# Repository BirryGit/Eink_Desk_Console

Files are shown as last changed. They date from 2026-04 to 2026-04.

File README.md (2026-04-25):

Screen_Holder_Thing_2026-Apr-03_04-33-51AM-000_CustomizedView44042802966_png

# Eink_Desk_Console
This is a project I am building to track my projects and show data from Home Assistant and other APIs. I wanted a small thing on my desk that I could glance at and see everything I could possibly want. I also wanted something to keep me on track with time sensitive projects. (So I therefore procrastinated with a project to reduce procrastination.) I don't really recommend anyone build this, because it is incredibly hyperspecific to my use case. Please use it for help and inspiration.

## APIs Needed
1. Open Weather
2. Home Assistant (Self Hosted)
3. Geoapify
4. Google Apps Script

## Bill Of Materials
| Name | Purpose | Quantity | Total Cost (USD) | Link | Distributor |
|---|---|---|---|---|---|
| M2 Bolts | Connecting everything together | 8 | 0.08 | | Amazon |
| USB C Cable | Power and data to the controller | 1 | 4.5 | | Anywhere |
| Xiao ESP32 S3 | Does all the beep booping in this project | 1 | 16.99 | https://www.amazon.com/ESP32S3-2-4GHz-Dual-core-Supported-Efficiency-Interface/dp/B0BYSB66S5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 | Amazon |
| M2 Heat Set Inserts | Adding Threads for 3d Prints | 8 | 0.24 | | Amazon |
| 7.5inch E-Ink Display | It is the main component in the project. It will show the data I need without using basically any power. | 1 | 75.15 | https://www.amazon.com/waveshare-7-5inch-HAT-Raspberry-Consumption/dp/B075R4QY3L#averageCustomerReviewsAnchor | Amazon |

## Wiring Diagram
Driver Board

## Assembly Instructions
1. Print all of the pieces needed (2 case, 1 base)
2. Use heat set inserts to add threads to the printed holes (8 holes on the bezel piece)
3. Place the screen within the bezel
4. Carefully place the backing print into the bezel to keep the screen in place
5. Screw bolts to keep the printed pieces together
6. Put the case into the base, and screw it in
7. Connect the electronics to the screen
   
### Assembly Animation

https://github.com/user-attachments/assets/f419b6c7-1fa8-42ba-b154-1aed95d2b339

Screen_Holder_Thing_2026-Apr-03_04-26-18AM-000_CustomizedView27974898632_png

Screen_Case_2026-Apr-02_05-09-52AM-000_CustomizedView14609026417_png

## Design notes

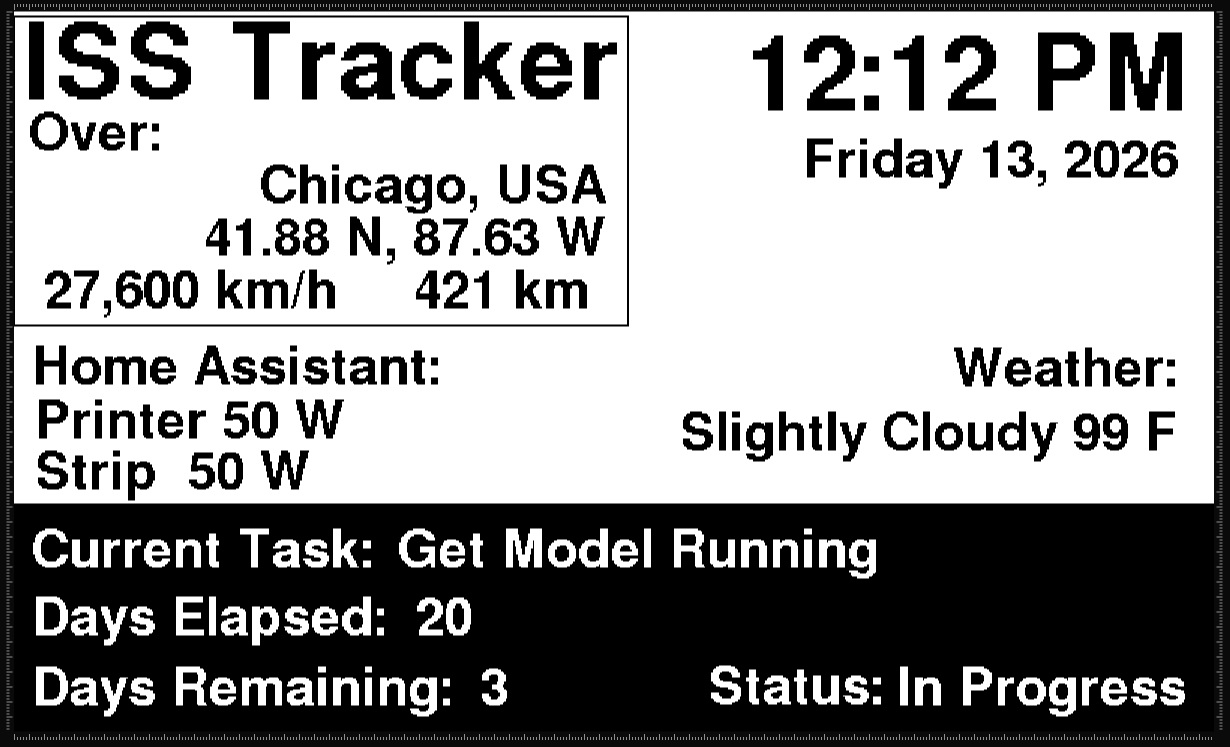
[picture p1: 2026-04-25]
UI/UI_Screenshot.png

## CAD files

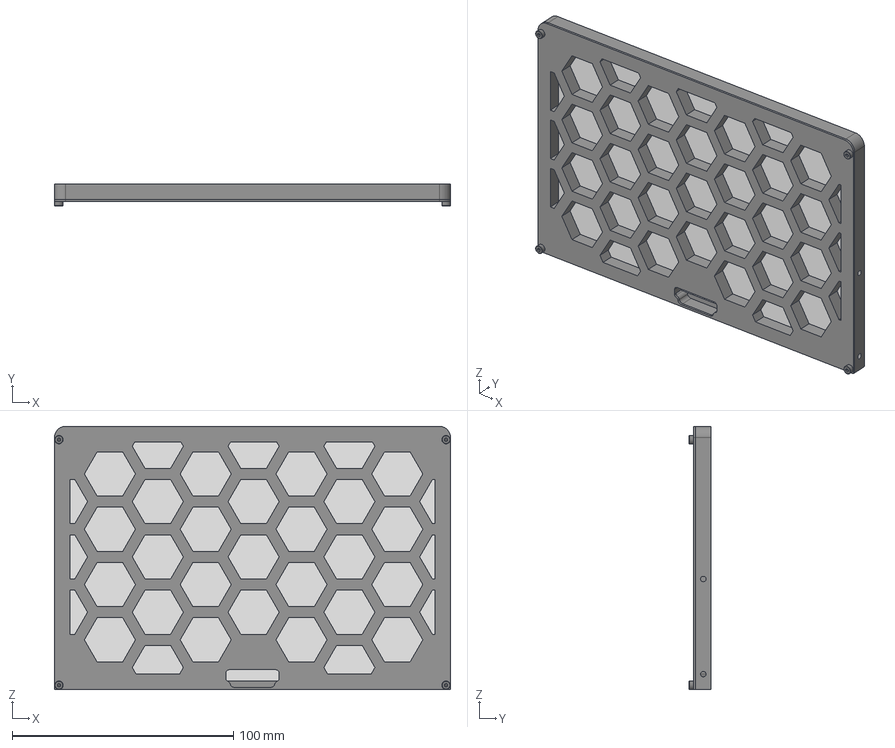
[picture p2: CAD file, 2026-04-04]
3d models/STEP/Screen Case.step
179.0 x 10.0 x 119.0 mm
BSHCS ASME B18.3.1M - M2x0.4 x 4 Steel Grade 2 Black x 4

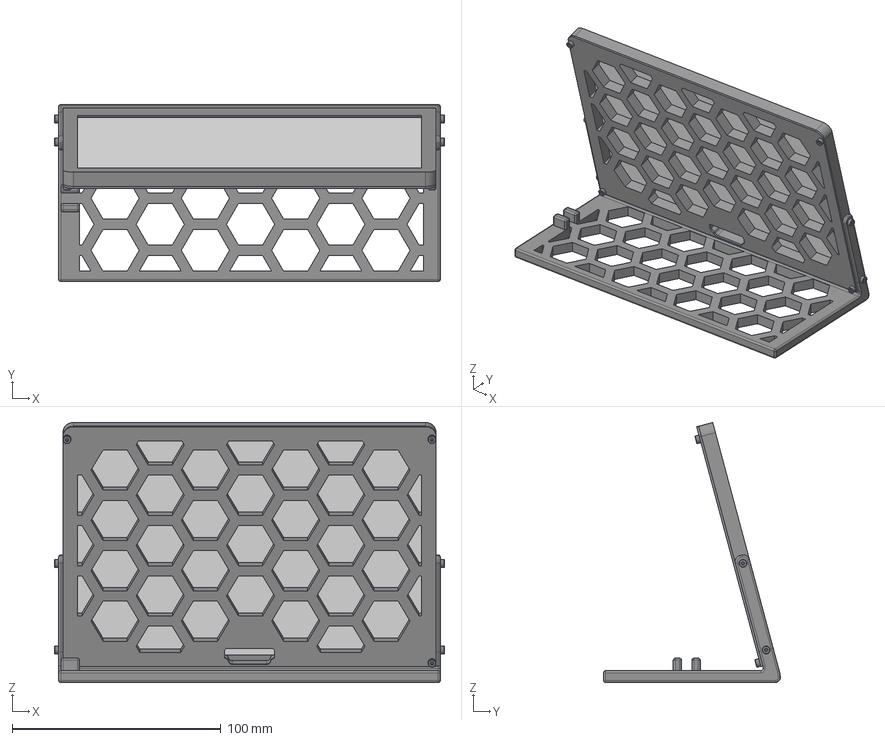
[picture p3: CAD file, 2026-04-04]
3d models/STEP/Base.step
187.0 x 84.9 x 124.7 mm
BSHCS ASME B18.3.1M - M2x0.4 x 4 Steel Grade 2 Black x 8

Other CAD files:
3d models/3MF/Base.3mf
3d models/3MF/Screen Case.3mf
3d models/Fusion/Base.f3z
3d models/Fusion/Screen Case.f3z

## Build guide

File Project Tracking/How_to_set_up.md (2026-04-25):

## Data
Replace the names and the dates with your data, and you should be set. You may need to expand the functions if you have more values.

## App Scripts
This is the harder part. All you need to do is go to Extensions at the top and select APP Scripts. From there, paste the code, and it should work. Put a Script Property in settings with the name "API_TOKEN". Then from deploy, deploy it as a web app, making sure to allow all access. Then copy the link and put it into the code!

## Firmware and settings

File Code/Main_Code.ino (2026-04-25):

#include <WiFi.h>
#include <WiFiClientSecure.h>
#include <HTTPClient.h>
#include <ArduinoJson.h>
#include <math.h>
#include <time.h>
#include <SPI.h>
#include <ctype.h>
#include <GxEPD2_BW.h>
#include <Fonts/FreeSansBold18pt7b.h>

//Wifi Credentials
const char* ssid = "YOUR_WIFI_NAME";
const char* password = "YOUR_WIFI_PASSWORD";

//Time Server Details
const char* ntpServer = "pool.ntp.org";
const char* tzInfo = "CST6CDT,M3.2.0/2,M11.1.0/2";

//ISS API Information
const char* issUrl = "https://api.wheretheiss.at/v1/satellites/25544";

const char* geoapifyApiKey = "YOUR_GEOAPIFY_KEY";

//Weather API Information
const char* weatherApiKey = "YOUR_OPENWEATHER_KEY";
const char* lat = "YOUR_LATITUDE";
const char* lon = "YOUR_LONGITUDE";

//Home assistant API information
const char* homeAssistantBaseUrl = "YOUR_HOME_ASSISTANT_URL";
const char* homeAssistantToken = "YOUR_HOME_ASSISTANT_TOKEN";

const char* printerPowerEntityId = "sensor.3d_printer_current_consumption";
const char* powerStripPowerEntityId = "sensor.tp_link_power_strip_current_consumption";

//Google Sheets API Link

const char* googleAPI = "YOUR_GOOGLE_SCRIPT_URL?token=YOUR_KEY_IN_APP_SCRIPT";

//Default Weather Values
float outsideTempF = 0.0f;
bool outsideTempValid = false;

char weatherMain[24] = "";
char weatherDescription[48] = "";
bool weatherConditionValid = false;

// Home Assistant default cached values
float printerPowerWatts = 0.0f;
bool printerPowerValid = false;

float powerStripPowerWatts = 0.0f;
bool powerStripPowerValid = false;

// ISS Data structure
struct IssData {
  bool valid;
  float latitude;
  float longitude;
  float altitudeKm;
  float velocityKmh;
  long timestamp;
  char overCountry[40];
};

//Schedule Data Structure
struct ScheduleData {
  char name[80];
  char manualStatus[32];
  char autoStatus[32];
  int daysSinceStart;
  int daysTillTaskEnd;
  bool valid;
};

ScheduleData scheduleData = {
  "Loading...",
  "--",
  "--",
  0,
  0,
  false
};

IssData issData = {false, 0.0f, 0.0f, 0.0f, 0.0f, 0, "Unknown"};

unsigned long lastClockCheck = 0;
const unsigned long clockCheckInterval = 1000; // once per second

unsigned long lastWeatherUpdate = 0;
const unsigned long weatherUpdateInterval = 10UL * 60UL * 1000UL; // every 10 minutes

unsigned long lastIssUpdate = 0;
const unsigned long issUpdateInterval = 60UL * 1000UL; // every minute

unsigned long lastHomeAssistantUpdate = 0;
const unsigned long homeAssistantUpdateInterval = 60UL * 1000UL; // every minute

const unsigned long scheduleUpdateInterval = 15UL * 60UL * 1000UL; // every 15 minutes
unsigned long lastScheduleUpdate = 0;

//Data Setup To make sure things actually happen
int lastDisplayedMinute = -1;
bool dashboardDirty = true;

/* Wiring:

  VCC -> 3V3
  GND -> GND
  DIN -> D9
  CLK -> D7
  CS -> D3
  DC -> D1
  RST -> D0
  BUSY -> D2
  PWR -> D5
*/
static const int PIN_EPD_BUSY = D2;
static const int PIN_EPD_RST  = D0;
static const int PIN_EPD_DC   = D1;
static const int PIN_EPD_CS   = D3;
static const int PIN_EPD_SCK  = D7;
static const int PIN_EPD_MOSI = D9;
static const int PIN_EPD_PWR  = D5;

// For newer GxEPD2 versions, 7.5 inch BW V2 is GxEPD2_750_GDEY075T7.
GxEPD2_BW<GxEPD2_750_GDEY075T7, GxEPD2_750_GDEY075T7::HEIGHT> display(
  GxEPD2_750_GDEY075T7(PIN_EPD_CS, PIN_EPD_DC, PIN_EPD_RST, PIN_EPD_BUSY)
);

void clearScreen(){
  //Make the whole screen white
  display.fillScreen(GxEPD_WHITE);
}

void drawWifiConnecting(){
  //Displays static black text "Wifi Connecting..."
  display.setTextColor(GxEPD_BLACK);
  display.setTextSize(5);
  display.setTextWrap(false);
  display.setFont(&FreeSansBold18pt7b);
  display.setCursor(231, 222);
  display.print("Wifi");

  display.setTextSize(3);
  display.setCursor(68, 388);
  display.print("Connecting...");
}

void drawTimeDate() {
  //Get the time info
  struct tm timeinfo;

  //Padding for correct alignment
  const int panelRight = 803;
  const int rightPadding = 20;

  const int timeRightEdge = panelRight - rightPadding;
  const int dateRightEdge = panelRight - rightPadding;

  const int timeBaselineY = 64;
  const int dateBaselineY = 110;

  //Set Text Info
  display.setFont(&FreeSansBold18pt7b);
  display.setTextColor(GxEPD_BLACK);
  display.setTextWrap(false);

  int16_t x1, y1;
  uint16_t w, h;

  //Is Everything Working?
  if (!getLocalTime(&timeinfo)) {
    display.setTextSize(2);
    display.getTextBounds("Time Unavailable", 0, 0, &x1, &y1, &w, &h);
    display.setCursor(timeRightEdge - w, timeBaselineY);
    display.print("Time Unavailable");

    display.setTextSize(1);
    display.getTextBounds("Date Unavailable", 0, 0, &x1, &y1, &w, &h);
    display.setCursor(dateRightEdge - w, dateBaselineY);
    display.print("Date Unavailable");
    return;
  }

  // Overkill memory managment
  char timeBuffer[16];
  char dateBuffer[40];

  //Format time
  int hour12 = timeinfo.tm_hour % 12;
  if (hour12 == 0) hour12 = 12;

  snprintf(
    timeBuffer,
    sizeof(timeBuffer),
    "%d:%02d %s",
    hour12,
    timeinfo.tm_min,
    (timeinfo.tm_hour >= 12) ? "PM" : "AM"
  );

  strftime(dateBuffer, sizeof(dateBuffer), "%A %d, %Y", &timeinfo);

  //Actually print data
  display.setTextSize(2);
  display.getTextBounds(timeBuffer, 0, 0, &x1, &y1, &w, &h);
  display.setCursor(timeRightEdge - w, timeBaselineY);
  display.print(timeBuffer);

  display.setTextSize(1);
  display.getTextBounds(dateBuffer, 0, 0, &x1, &y1, &w, &h);
  display.setCursor(dateRightEdge - w, dateBaselineY);
  display.print(dateBuffer);
}



void drawISSTracker(const IssData& data) {
  //Epic outline. (Graphics Design is my passion)
  display.drawRect(0, 0, 410, 207, GxEPD_BLACK);

  //Font Info
  display.setFont(&FreeSansBold18pt7b);
  display.setTextColor(GxEPD_BLACK);
  display.setTextWrap(false);

  //Label
  display.setTextSize(2);
  display.setCursor(4, 57);
  display.print("ISS Tracker");

  //Make Text Smaller for Values
  display.setTextSize(1);

  // Fixed layout anchors for alignment
  const int overLabelX = 10;
  const int overLabelY = 92;

  const int countryRightEdge = 395;
  const int countryBaselineY = 127;

  const int coordRightEdge = 395;
  const int coordBaselineY = 162;

  const int speedLeftX = 20;
  const int speedBaselineY = 197;

  const int altitudeRightEdge = 395;
  const int altitudeBaselineY = 197;

  int16_t x1, y1;
  uint16_t w, h;

  display.setCursor(overLabelX, overLabelY);
  display.print("Over:");

  //Memory Managment
  char countryBuffer[40];
  char coordBuffer[40];
  char altitudeBuffer[20];
  char speedBuffer[24];

  char latHemisphere = (data.latitude >= 0) ? 'N' : 'S';
  char lonHemisphere = (data.longitude >= 0) ? 'E' : 'W';

  //Make Sure Everything is Good and Actually Exists
  if (!data.valid) {
    strncpy(countryBuffer, "Unknown", sizeof(countryBuffer) - 1);
    countryBuffer[sizeof(countryBuffer) - 1] = '\0';

    strncpy(coordBuffer, "--.--, --.--", sizeof(coordBuffer) - 1);
    coordBuffer[sizeof(coordBuffer) - 1] = '\0';

    strncpy(altitudeBuffer, "-- km", sizeof(altitudeBuffer) - 1);
    altitudeBuffer[sizeof(altitudeBuffer) - 1] = '\0';

    strncpy(speedBuffer, "-- km/h", sizeof(speedBuffer) - 1);
    speedBuffer[sizeof(speedBuffer) - 1] = '\0';
  } else {
    snprintf(countryBuffer, sizeof(countryBuffer), "%s", data.overCountry);
    snprintf( coordBuffer, sizeof(coordBuffer), "%.2f %c, %.2f %c", fabs(data.latitude), latHemisphere, fabs(data.longitude), lonHemisphere);
    snprintf(altitudeBuffer, sizeof(altitudeBuffer), "%d km", (int)round(data.altitudeKm));
    snprintf(speedBuffer, sizeof(speedBuffer), "%d km/h", (int)round(data.velocityKmh));
  }
  
  //Alignment uses math and stuff to get into the right spot
  // Country: right-aligned
  display.getTextBounds(countryBuffer, 0, 0, &x1, &y1, &w, &h);
  display.setCursor(countryRightEdge - w, countryBaselineY);
  display.print(countryBuffer);

  // Coordinates: right-aligned
  display.getTextBounds(coordBuffer, 0, 0, &x1, &y1, &w, &h);
  display.setCursor(coordRightEdge - w, coordBaselineY);
  display.print(coordBuffer);

  // Speed: left-aligned on left side
  display.setCursor(speedLeftX, speedBaselineY);
  display.print(speedBuffer);

  // Altitude: right-aligned on right side
  display.getTextBounds(altitudeBuffer, 0, 0, &x1, &y1, &w, &h);
  display.setCursor(altitudeRightEdge - w, altitudeBaselineY);
  display.print(altitudeBuffer);
}



void drawWeather(float outsideTempFValue, bool outsideTempIsValid, const char* conditionText, bool conditionIsValid){
  //Alignment Stuff
  const int panelRight = 803;
  const int rightPadding = 20;
  const int weatherRightEdge = panelRight - rightPadding;

  const int labelBaselineY = 249;
  const int dataBaselineY = 290;
  
  //Font Stuff
  display.setTextSize(1);
  display.setFont(&FreeSansBold18pt7b);
  display.setTextColor(GxEPD_BLACK);
  display.setTextWrap(false);

  int16_t x1, y1;
  uint16_t w, h;

  //Memory Managment
  char weatherLine[80];

  const char* safeCondition = conditionIsValid ? conditionText : "--";

  //Is Everything OK?
  if (outsideTempIsValid) {
    snprintf(
      weatherLine,
      sizeof(weatherLine),
      "%s %d F",
      safeCondition,
      (int)round(outsideTempFValue)
    );
  } else {
    snprintf(
      weatherLine,
      sizeof(weatherLine),
      "%s -- F",
      safeCondition
    );
  }

  //Print Text
  display.getTextBounds("Weather:", 0, 0, &x1, &y1, &w, &h);
  display.setCursor(weatherRightEdge - w, labelBaselineY);
  display.print("Weather:");

  display.getTextBounds(weatherLine, 0, 0, &x1, &y1, &w, &h);
  display.setCursor(weatherRightEdge - w, dataBaselineY);
  display.print(weatherLine);
}

void drawScheduleDisplay() {
  //Black Background
  display.fillRect(0, 328, 803, 152, GxEPD_BLACK);

  //Font Info
  display.setTextSize(1);
  display.setFont(&FreeSansBold18pt7b);
  display.setTextColor(GxEPD_WHITE);
  display.setTextWrap(false);

  //Current Task Label
  display.setCursor(12, 370);
  display.print("Current Task:");

  //Current Task
  display.setCursor(256, 370);
  if (scheduleData.valid) {
    display.print(scheduleData.name);
  } else {
    display.print("Schedule Unavailable");
  }

  //That is the same for the rest :D
  display.setCursor(12, 415);
  display.print("Days Elapsed:");

  display.setCursor(268, 415);
  if (scheduleData.valid) {
    display.print(scheduleData.daysSinceStart);
  } else {
    display.print("--");
  }

  display.setCursor(12, 462);
  display.print("Days Remaining:");

  display.setCursor(311, 462);
  if (scheduleData.valid) {
    display.print(scheduleData.daysTillTaskEnd);
  } else {
    display.print("--");
  }

  display.setCursor(470, 462);
  display.print("Status:");

  display.setCursor(595, 462);
  if (scheduleData.valid) {
    display.print(scheduleData.manualStatus);
  } else {
    display.print("--");
  }
}

void drawHomeAssistantData(float printerWatts, bool printerValid, float stripWatts, bool stripValid) {
  //Font Info
  display.setTextSize(1);
  display.setFont(&FreeSansBold18pt7b);
  display.setTextColor(GxEPD_BLACK);

  //Label
  display.setCursor(12, 244);
  display.print("Home Assistant:");

  //Printer Label and Value
  display.setCursor(14, 280);
  display.print("Printer");
  display.setCursor(139, 280);
  if (printerValid) {
    display.print((int)round(printerWatts));
    display.print(" W");
  } else {
    display.print("-- W");
  }

  //Power Strip Label and Value
  display.setCursor(14, 315);
  display.print("Strip");
  display.setCursor(116, 315);
  if (stripValid) {
    display.print((int)round(stripWatts));
    display.print(" W");
  } else {
    display.print("-- W");
  }
}

void drawDashboard() {
  //Draw Everything with the correct data
  display.firstPage();
  do {
    clearScreen();
    drawTimeDate();
    drawISSTracker(issData);
    drawWeather(outsideTempF, outsideTempValid, weatherDescription, weatherConditionValid);
    drawScheduleDisplay();
    drawHomeAssistantData(printerPowerWatts, printerPowerValid, powerStripPowerWatts, powerStripPowerValid);
  }
  while (display.nextPage());
}

//---API call updates---

void checkClockForDisplayUpdate() {
  struct tm timeinfo;

  if (!getLocalTime(&timeinfo)) {
    return;
  }

  if (timeinfo.tm_min != lastDisplayedMinute) {
    lastDisplayedMinute = timeinfo.tm_min;
    dashboardDirty = true;
  }
}

// Home assistant call function
bool fetchHomeAssistantWatts(const char* entityId, float& wattsOut, bool& validOut) {
  //Ensure Wifi not dead
  if (WiFi.status() != WL_CONNECTED) {
    return false;
  }
  
  // Get data from HA
  String url = String(homeAssistantBaseUrl) + "/api/states/" + entityId;

  HTTPClient http;
  http.begin(url);
  http.addHeader("Authorization", String("Bearer ") + homeAssistantToken);
  http.addHeader("Content-Type", "application/json");

  int httpCode = http.GET();
  if (httpCode != 200) {
    http.end();
    validOut = false;
    return false;
  }

  String payload = http.getString();
  http.end();

  DynamicJsonDocument doc(2048);
  DeserializationError error = deserializeJson(doc, payload);
  if (error) {
    validOut = false;
    return false;
  }

  //Grab Data and make sure its good
  const char* stateText = doc["state"] | "";
  if (strlen(stateText) == 0 ||
      strcmp(stateText, "unknown") == 0 ||
      strcmp(stateText, "unavailable") == 0 ||
      strcmp(stateText, "none") == 0) {
    validOut = false;
    return false;
  }

  float newWatts = atof(stateText);
  bool changed = (!validOut) || ((int)round(newWatts) != (int)round(wattsOut));

  wattsOut = newWatts;
  validOut = true;

  return changed;
}

//Calls Home Assistant API functions with params
bool updateHomeAssistantData() {
  bool printerChanged = fetchHomeAssistantWatts(
    printerPowerEntityId,
    printerPowerWatts,
    printerPowerValid
  );

  bool stripChanged = fetchHomeAssistantWatts(
    powerStripPowerEntityId,
    powerStripPowerWatts,
    powerStripPowerValid
  );

  return printerChanged || stripChanged;
}

bool updateWeatherData() {
  //Ensure Wifi connected
  if (WiFi.status() != WL_CONNECTED) {
    return false;
  }

  //Make API URL and Get the Data
  String url = String("https://api.openweathermap.org/data/2.5/weather?lat=") + lat + "&lon=" + lon + "&appid=" + weatherApiKey + "&units=imperial";

  HTTPClient http;
  http.begin(url);

  int httpCode = http.GET();
  if (httpCode != 200) {
    http.end();
    return false;
  }

  String payload = http.getString();
  http.end();
  DynamicJsonDocument doc(2048);
  DeserializationError error = deserializeJson(doc, payload);
  if (error) {
    return false;
  }

  //Extract Data and check if it is ok and changed
  float newTempF = doc["main"]["temp"] | NAN;
  const char* newMain = doc["weather"][0]["main"] | "";
  const char* newDescription = doc["weather"][0]["description"] | "";

  if (isnan(newTempF) || strlen(newMain) == 0) {
    return false;
  }

  bool tempChanged =
    (!outsideTempValid) ||
    ((int)round(newTempF) != (int)round(outsideTempF));

  bool conditionChanged =
    (!weatherConditionValid) ||
    (strcmp(weatherMain, newMain) != 0) ||
    (strcmp(weatherDescription, newDescription) != 0);

  //Set New Values
  outsideTempF = newTempF;
  outsideTempValid = true;

  strncpy(weatherMain, newMain, sizeof(weatherMain) - 1);
  weatherMain[sizeof(weatherMain) - 1] = '\0';

  strncpy(weatherDescription, newDescription, sizeof(weatherDescription) - 1);
  weatherDescription[sizeof(weatherDescription) - 1] = '\0';
  if (weatherDescription[0] != '\0') {
    weatherDescription[0] = toupper(weatherDescription[0]);
  }

  weatherConditionValid = true;

  return tempChanged || conditionChanged;
}

bool updateIssCountry(float latValue, float lonValue, char* countryOut, size_t countryOutSize) {
  //Ensure Connection
  if (WiFi.status() != WL_CONNECTED) {
    return false;
  }

  //Get the Data
  String url = String("https://api.geoapify.com/v1/geocode/reverse?lat=") + String(latValue, 6) + "&lon=" + String(lonValue, 6) + "&type=country&format=json&limit=1&lang=en&apiKey=" + geoapifyApiKey;

  HTTPClient http;
  http.begin(url);

  int httpCode = http.GET();
  if (httpCode != 200) {
    http.end();
    return false;
  }

  String payload = http.getString();
  http.end();

  DynamicJsonDocument doc(4096);
  DeserializationError error = deserializeJson(doc, payload);
  if (error) {
    return false;
  }

  //Extract information
  if (!doc["results"].is<JsonArray>() || doc["results"].size() == 0) {
    strncpy(countryOut, "Ocean", countryOutSize - 1);
    countryOut[countryOutSize - 1] = '\0';
    return true;
  }

  const char* fullCountryName = doc["results"][0]["country"] | "";
  if (strlen(fullCountryName) == 0) {
    strncpy(countryOut, "Unknown", countryOutSize - 1);
    countryOut[countryOutSize - 1] = '\0';
    return true;
  }

  strncpy(countryOut, fullCountryName, countryOutSize - 1);
  countryOut[countryOutSize - 1] = '\0';
  return true;
}

bool updateIssData() {
  //Ensure Wifi Connection
  if (WiFi.status() != WL_CONNECTED) {
    return false;
  }

  //Call Endpoint
  HTTPClient http;
  http.begin(issUrl);

  int httpCode = http.GET();
  if (httpCode != 200) {
    http.end();
    return false;
  }

  String payload = http.getString();
  http.end();

  DynamicJsonDocument doc(2048);
  DeserializationError error = deserializeJson(doc, payload);
  if (error) {
    return false;
  }

  //Extract Data
  float newLatitude = doc["latitude"] | NAN;
  float newLongitude = doc["longitude"] | NAN;
  float newAltitudeKm = doc["altitude"] | NAN;
  float newVelocityKmh = doc["velocity"] | NAN;
  long newTimestamp = doc["timestamp"] | 0;

  //Checks that values are numbers
  if (isnan(newLatitude) || isnan(newLongitude) || isnan(newAltitudeKm) || isnan(newVelocityKmh)) {
    return false;
  }

  //Update The country the ISS is over
  char newCountry[40];
  strncpy(newCountry, issData.overCountry, sizeof(newCountry) - 1);
  newCountry[sizeof(newCountry) - 1] = '\0';

  updateIssCountry(newLatitude, newLongitude, newCountry, sizeof(newCountry));

  //Checks if values have changed
  bool changed =
    (!issData.valid) ||
    ((int)round(newLatitude * 100) != (int)round(issData.latitude * 100)) ||
    ((int)round(newLongitude * 100) != (int)round(issData.longitude * 100)) ||
    ((int)round(newAltitudeKm) != (int)round(issData.altitudeKm)) ||
    ((int)round(newVelocityKmh) != (int)round(issData.velocityKmh)) ||
    (strcmp(issData.overCountry, newCountry) != 0);  
    //Updates Data into structure
    issData.latitude = newLatitude;
    issData.longitude = newLongitude;
    issData.altitudeKm = newAltitudeKm;
    issData.velocityKmh = newVelocityKmh;
    issData.timestamp = newTimestamp;
    issData.valid = true;

    strncpy(issData.overCountry, newCountry, sizeof(issData.overCountry) - 1);
    issData.overCountry[sizeof(issData.overCountry) - 1] = '\0';

    return changed;
}

bool updateScheduleData() {
  //Ensure Wifi Connection
  if (WiFi.status() != WL_CONNECTED) {
    return false;
  }

  //Let Google Redirect Because it apperently is like that sometimes
  HTTPClient http;
  http.setFollowRedirects(HTTPC_STRICT_FOLLOW_REDIRECTS);
  http.begin(googleAPI);

  //Get the Data
  int httpCode = http.GET();
  if (httpCode != 200) {
    http.end();
    return false;
  }

  String payload = http.getString();
  http.end();

  DynamicJsonDocument doc(2048);
  DeserializationError error = deserializeJson(doc, payload);
  if (error) {
    return false;
  }
  //Do the Data stuff
  const char* newName = doc["name"] | "";
  const char* newStatus = doc["status"] | "";
  int newDaysElapsed = doc["daysSinceStart"] | -1;
  int newDaysRemaining = doc["daysTillTaskEnd"] | -1;

  if (strlen(newName) == 0 || strlen(newStatus) == 0 ||
      newDaysElapsed < 0 || newDaysRemaining < 0) {
    return false;
  }

  bool changed =
    (!scheduleData.valid) ||
    (strcmp(scheduleData.name, newName) != 0) ||
    (strcmp(scheduleData.manualStatus, newStatus) != 0) ||
    (scheduleData.daysSinceStart != newDaysElapsed) ||
    (scheduleData.daysTillTaskEnd != newDaysRemaining);

  strncpy(scheduleData.name, newName, sizeof(scheduleData.name) - 1);
  scheduleData.name[sizeof(scheduleData.name) - 1] = '\0';

  strncpy(scheduleData.manualStatus, newStatus, sizeof(scheduleData.manualStatus) - 1);
  scheduleData.manualStatus[sizeof(scheduleData.manualStatus) - 1] = '\0';

  scheduleData.daysSinceStart = newDaysElapsed;
  scheduleData.daysTillTaskEnd = newDaysRemaining;
  scheduleData.valid = true;

  return changed;
}
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
void loop() {
  unsigned long now = millis();

  //Make Sure Clock Gets Updated
  if (now - lastClockCheck >= clockCheckInterval) {
    lastClockCheck = now;
    checkClockForDisplayUpdate();
  }

  //Weather Data Update
  if (now - lastWeatherUpdate >= weatherUpdateInterval) {
    lastWeatherUpdate = now;
    if (updateWeatherData()) {
      dashboardDirty = true;
    }
  }

  //ISS Data Update
  if (now - lastIssUpdate >= issUpdateInterval) {
    lastIssUpdate = now;
    if (updateIssData()) {
      dashboardDirty = true;
    }
  }

  //Home Assistant Data Update
  if (now - lastHomeAssistantUpdate >= homeAssistantUpdateInterval) {
    lastHomeAssistantUpdate = now;
    if (updateHomeAssistantData()) {
      dashboardDirty = true;
    }
  }

  //Google Sheets Schedule Update
  if (now - lastScheduleUpdate >= scheduleUpdateInterval) {
    lastScheduleUpdate = now;
    if (updateScheduleData()) {
      dashboardDirty = true;
    }
  }
  
  // Checks to see if any data has changed, and therefore needs to be changed.
  if (dashboardDirty) {
    dashboardDirty = false;
    drawDashboard();
  }

  //Delay for 50 milliseconds, so the microcontroller doesn't explode trying to do everything 200 times per second
  delay(50);
}

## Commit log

2026-04-04 Added 3mf files
    [Screen Case.3mf, Screen Holder Thing.3mf]
2026-04-04 Added fusion files
    [Screen Case.f3z, Screen Holder Thing.f3z]
2026-04-04 moved 3d files
    [Screen Case.3mf]
2026-04-04 Moved 3d models
    [Screen Holder Thing.f3z]
2026-04-06 Add assembly instructions and animation section
    Added assembly instructions for the project.
2026-04-06 Added an assembly video
2026-04-06 Rename Assembly Video.mp4 to Media/Assembly Video.mp4
2026-04-06 Add assembly animation link to README
    Added a link to the assembly animation for better guidance.
2026-04-06 Correct README punctuation and formatting
    Fixed punctuation in assembly instructions and project description.
2026-04-25 Added API list and BOM
    Added APIs needed and Bill of Materials sections to README.
2026-04-25 Adding Google Sheet Template
    [Empty Project timeline.xlsx]
2026-04-25 Rename Empty Project timeline.xlsx to Project Tracking/Empty Project timeline.xlsx
    [Empty Project timeline.xlsx]
2026-04-25 Revise project description and added wiring diagram and renders
    Updated project description to clarify its specific use case and added a wiring diagram section with an image.
2026-04-25 Added BOM File
    [Bill_Of_Materials.csv]
